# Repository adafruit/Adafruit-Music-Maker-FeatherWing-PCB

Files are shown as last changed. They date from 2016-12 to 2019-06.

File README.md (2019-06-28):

## Adafruit Music Maker FeatherWing PCB

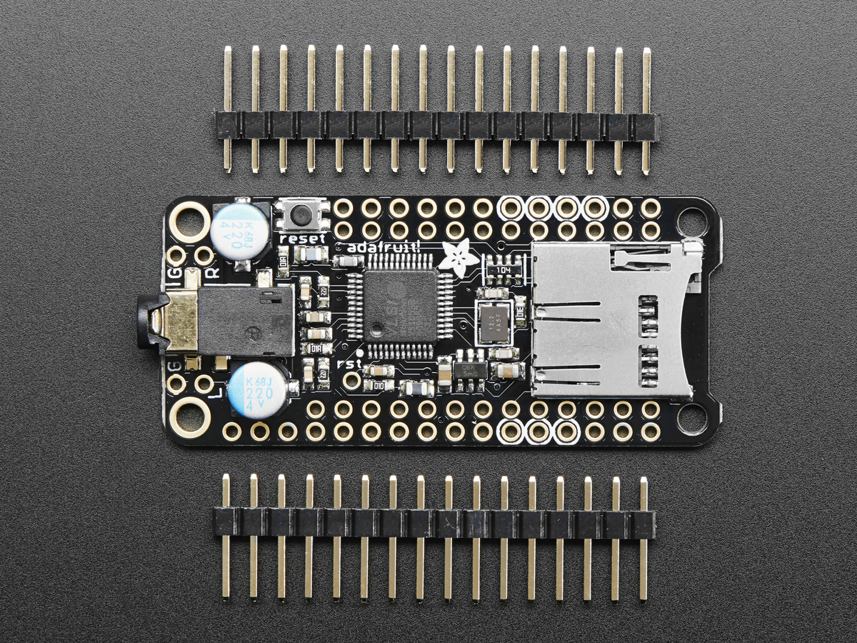
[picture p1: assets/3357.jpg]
<a href="http://www.adafruit.com/products/3357">&nbsp; 
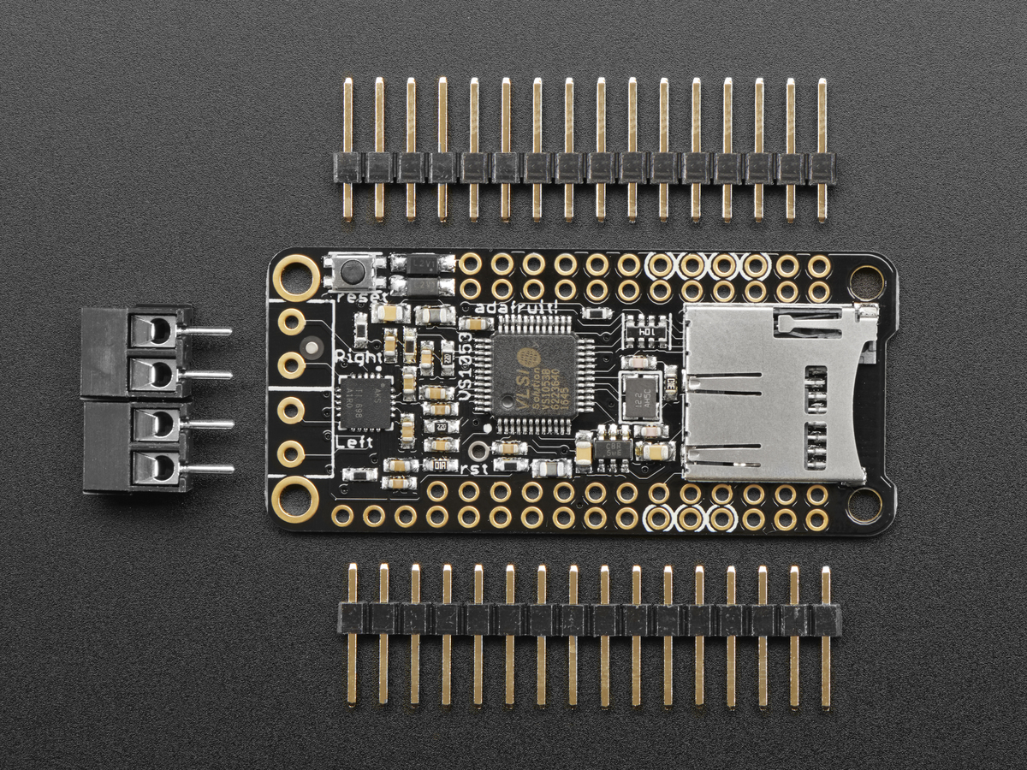
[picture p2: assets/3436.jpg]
<a href="http://www.adafruit.com/products/3436"><br/>
Click a picture to purchase from the Adafruit shop</a>

PCB files for the Adafruit Music Maker FeatherWings. Format is EagleCAD schematic and board layout

For more details, check out the product pages at
  * Music Maker FeatherWing http://www.adafruit.com/products/3357
  * Music Maker FeatherWing with 3W amp http://www.adafruit.com/products/3436

### Description

Bend all audio files to your will with the Adafruit Music Maker FeatherWings! It's a fun-size version of our Music Maker shield for Arduino! This powerful wing features the VS1053, an encoding/decoding (codec) chip that can decode a wide variety of audio formats such as MP3, AAC, Ogg Vorbis, WMA, MIDI, FLAC, WAV (PCM and ADPCM). You can do all sorts of stuff with the audio as well such as adjusting bass, treble, and volume digitally.

All this functionality is implemented in a light-weight SPI interface so that any Feather Board can play audio from an SD card. There's also a special MIDI mode that you can boot the chip into that will read 'classic' 31250Kbaud MIDI data from the UART TX pin and act like a synth/drum machine - there are dozens of built-in drum and sample effects!

What a great musical add-on to your Feather! That's why we spun up this super FeatherWing, perfect for use with any of our Feather Boards! Music playback testing working with ATmega32u4, ATSAMD M0, ESP8266, WICED Teensy 3, and nRF52 Feathers. MIDI playback works with all Feathers but you may need to remove the 'Wing during programming and also for USB-Serial Feathers like the ESP8266 and nRF52 you'll end up re-using the main Serial console for MIDI which can be confusing.

### License

Adafruit invests time and resources providing this open source design, please support Adafruit and open-source hardware by purchasing products from [Adafruit](https://www.adafruit.com)!

Designed by Limor Fried/Ladyada for Adafruit Industries.

Creative Commons Attribution/Share-Alike, all text above must be included in any redistribution. See license.txt for additional details.

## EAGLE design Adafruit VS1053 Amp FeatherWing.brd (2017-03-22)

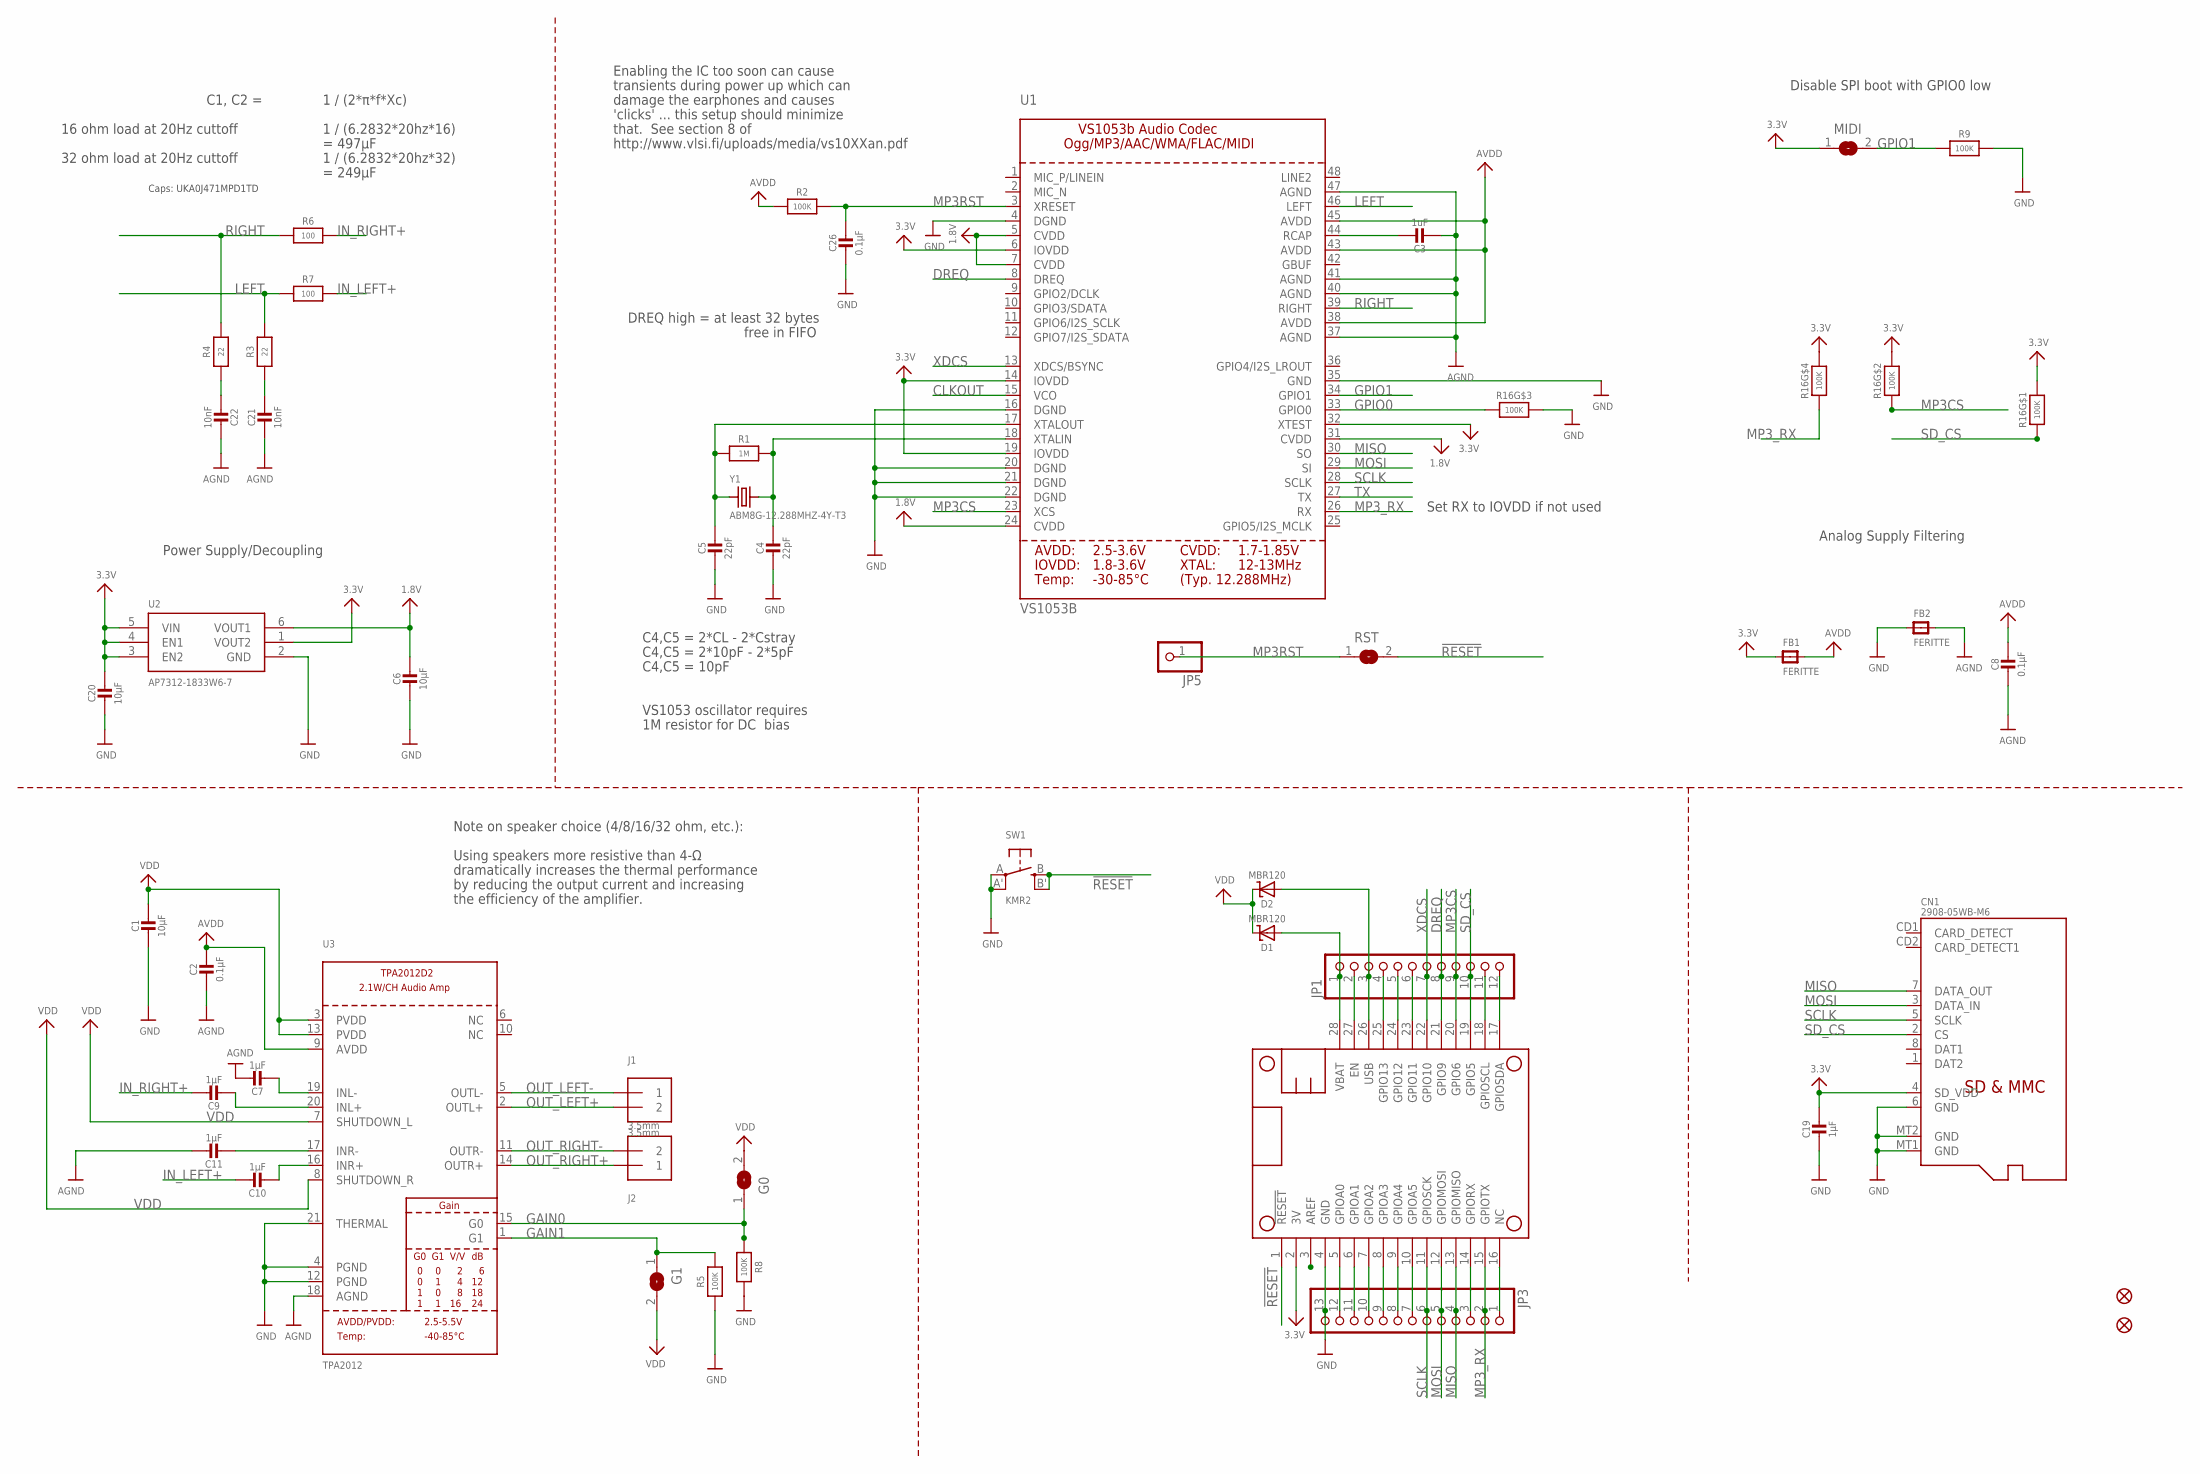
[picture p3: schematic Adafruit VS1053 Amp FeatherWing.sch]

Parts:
C1, C20: 10µF; 0805-NO
C2, C8, C26: 0.1µF; 0603-NO
C3: 1uF; 0603-NO
C4, C5: 22pF; 0603-NO
C6: 10µF; _0805MP
C7, C9, C10, C11, C19: 1µF; 0603-NO
C21, C22: 10nF; 0603-NO
CN1: 2908-05WB-M6; MICROSD
D1, D2: MBR120; SOD-123
FB1, FB2: FERITTE; 0805-NO
FID1, FID2: FIDUCIAL""; FIDUCIAL_1MM
G0, G1: SOLDERJUMPER; SOLDERJUMPER_ARROW_NOPASTE
J1, J2: 3.5mm; TERMBLOCK_1X2-3.5MM
JP1: HEADER-1X12; 1X12_ROUND
JP3: HEADER-1X13; 1X13_ROUND_70
JP5: HEADER-1X1ROUND; 1X01_ROUND
MIDI: SOLDERJUMPER; SOLDERJUMPER_ARROW_NOPASTE
MS1: FEATHERWING_NODIM
R1: 1M; 0603-NO
R2, R5, R8: 100K; 0603-NO
R3, R4: 22; 0603-NO
R6, R7: 100; 0603-NO
R9: 100K; _0603MP
R16: 100K; RESPACK_4X0603
RST: SOLDERJUMPERCLOSED; SOLDERJUMPER_CLOSEDWIRE
SW1: KMR2; BTN_KMR2_4.6X2.8
U1: VS1053B; LQFP48
U2: AP7312-1833W6-7; SOT23-6
U3: TPA2012; WQFN20
Y1: ABM8G-12.288MHZ-4Y-T3; CRYSTAL_3.2X2.5

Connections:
1.8V: C6.1, U1.5 (CVDD), U1.7 (CVDD), U1.24 (CVDD), U1.31 (CVDD), U2.6 (VOUT1)
3.3V: C19.1, C20.1, CN1.4 (SD_VDD), FB1.1, MIDI.1, MS1.2 (3V), R16.5 (2), R16.7 (2), R16.8 (2), U1.6 (IOVDD), U1.14 (IOVDD), U1.19 (IOVDD), U1.32 (XTEST), U2.1 (VOUT2), U2.3 (EN2), U2.4 (EN1), U2.5 (VIN)
!RESET: MS1.1 (!RESET), RST.2, SW1.B (S), SW1.B' (S1)
A: JP3.12, MS1.5 (GPIOA0)
AGND: C2.2, C3.2, C7.1, C8.2, C11.1, C21.2, C22.2, FB2.2, U1.37 (AGND), U1.40 (AGND), U1.41 (AGND), U1.47 (AGND), U3.18 (AGND)
AREF: MS1.3 (AREF)
AVDD: C2.1, C8.1, FB1.2, R2.1, U1.38 (AVDD), U1.43 (AVDD), U1.45 (AVDD), U3.9 (AVDD)
B: JP3.11, MS1.6 (GPIOA1)
C: JP3.10, MS1.7 (GPIOA2)
CLKOUT: U1.15 (VCO)
D: JP3.9, MS1.8 (GPIOA3)
DREQ: JP1.8, MS1.21 (GPIO9), U1.8 (DREQ)
E: JP3.8, MS1.9 (GPIOA4)
EN: JP1.2, MS1.27 (EN)
F: JP3.7, MS1.10 (GPIOA5)
G: JP3.1, MS1.16 (NC)
GAIN0: G0.1, R8.1, U3.15 (G0)
GAIN1: G1.1, R5.2, U3.1 (G1)
GND: C1.2, C4.2, C5.2, C6.2, C19.2, C20.2, C26.2, CN1.6 (GND), CN1.MT1 (GND), CN1.MT2 (GND), FB2.1, JP3.13, MS1.4 (GND), R5.1, R8.2, R9.2, R16.6 (2), SW1.A, SW1.A' (P1), U1.4 (DGND), U1.16 (DGND), U1.20 (DGND), U1.21 (DGND), U1.22 (DGND), U1.35 (GND), U2.2 (GND), U3.4 (PGND), U3.12 (PGND), U3.21 (THERMAL)
GPIO0: R16.3 (1), U1.33 (GPIO0)
GPIO1: MIDI.2, R9.1, U1.34 (GPIO1)
IN_LEFT+: C10.1, R7.1
IN_RIGHT+: C9.1, R6.1
L: JP1.6, MS1.23 (GPIO11)
LEFT: R3.1, R7.2, U1.46 (LEFT)
M: JP1.5, MS1.24 (GPIO12)
MISO: CN1.7 (DATA_OUT), JP3.4, MS1.13 (GPIOMISO), U1.30 (SO)
MOSI: CN1.3 (DATA_IN), JP3.5, MS1.12 (GPIOMOSI), U1.29 (SI)
MP3CS: JP1.9, MS1.20 (GPIO6), R16.2 (1), U1.23 (XCS)
MP3RST: C26.1, JP5.1, R2.2, RST.1, U1.3 (XRESET)
MP3_RX: JP3.2, MS1.15 (GPIOTX), R16.4 (1), U1.26 (RX)
N: JP1.4, MS1.25 (GPIO13)
unnamed: C5.1, R1.1, U1.17 (XTALOUT), Y1.1
unnamed: C4.1, R1.2, U1.18 (XTALIN), Y1.2
unnamed: C3.1, U1.44 (RCAP)
unnamed: C21.1, R3.2
unnamed: C22.1, R4.2
unnamed: C9.2, U3.20 (INL+)
unnamed: C7.2, U3.19 (INL-)
unnamed: C11.2, U3.17 (INR-)
unnamed: C10.2, U3.16 (INR+)
OUT_LEFT+: J1.2, U3.2 (OUTL+)
OUT_LEFT-: J1.1, U3.5 (OUTL-)
OUT_RIGHT+: J2.1, U3.14 (OUTR+)
OUT_RIGHT-: J2.2, U3.11 (OUTR-)
RIGHT: R4.1, R6.2, U1.39 (RIGHT)
SCL: JP1.11, MS1.18 (GPIOSCL)
SCLK: CN1.5 (SCLK), JP3.6, MS1.11 (GPIOSCK), U1.28 (SCLK)
SDA: JP1.12, MS1.17 (GPIOSDA)
SD_CS: CN1.2 (CS), JP1.10, MS1.19 (GPIO5), R16.1
TX: U1.27 (TX)
UART_RX: JP3.3, MS1.14 (GPIORX)
USB: D2.A, JP1.3, MS1.26 (USB)
VBAT: D1.A, JP1.1, MS1.28 (VBAT)
VDD: C1.1, D1.C, D2.C, G0.2, G1.2, U3.3 (PVDD), U3.7 (SHUTDOWN_L), U3.8 (SHUTDOWN_R), U3.13 (PVDD)
XDCS: JP1.7, MS1.22 (GPIO10), U1.13 (XDCS/BSYNC)

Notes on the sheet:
Analog Supply Filtering
C4,C5 = 2*CL - 2*Cstray
C4,C5 = 2*10pF - 2*5pF
C4,C5 = 10pF
VS1053 oscillator requires
1M resistor for DC bias
Set RX to IOVDD if not used
DREQ high = at least 32 bytes
Power Supply/Decoupling
transients during power up which can
damage the earphones and causes
'clicks' ... this setup should minimize
that. See section 8 of
http://www.vlsi.fi/uploads/media/vs10XXan.pdf
Enabling the IC too soon can cause
free in FIFO
Disable SPI boot with GPIO0 low
1 / (2*π*f*Xc)
16 ohm load at 20Hz cuttoff
1 / (6.2832*20hz*16)
C1, C2 =
= 497µF
32 ohm load at 20Hz cuttoff
1 / (6.2832*20hz*32)
= 249µF
Caps: UKA0J471MPD1TD
Using speakers more resistive than 4-Ω
dramatically increases the thermal performance
by reducing the output current and increasing
the efficiency of the amplifier.
Note on speaker choice (4/8/16/32 ohm, etc.):

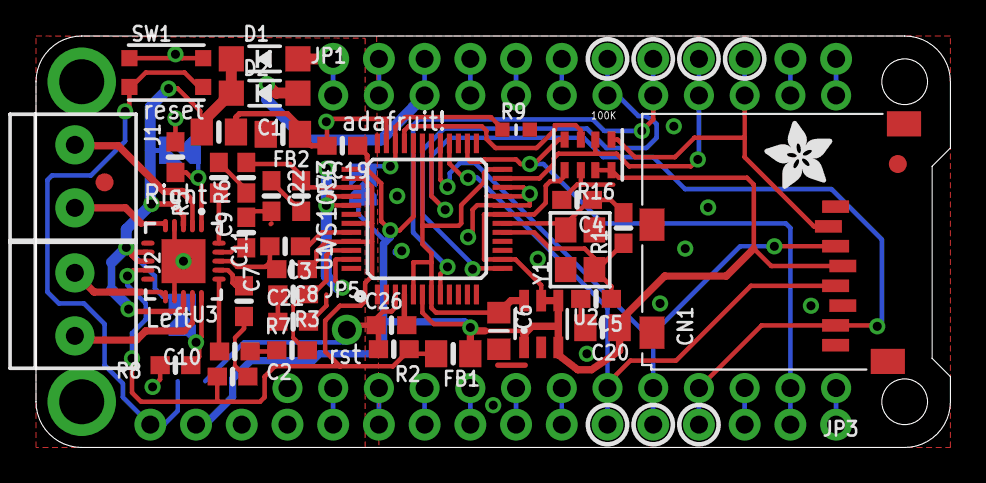
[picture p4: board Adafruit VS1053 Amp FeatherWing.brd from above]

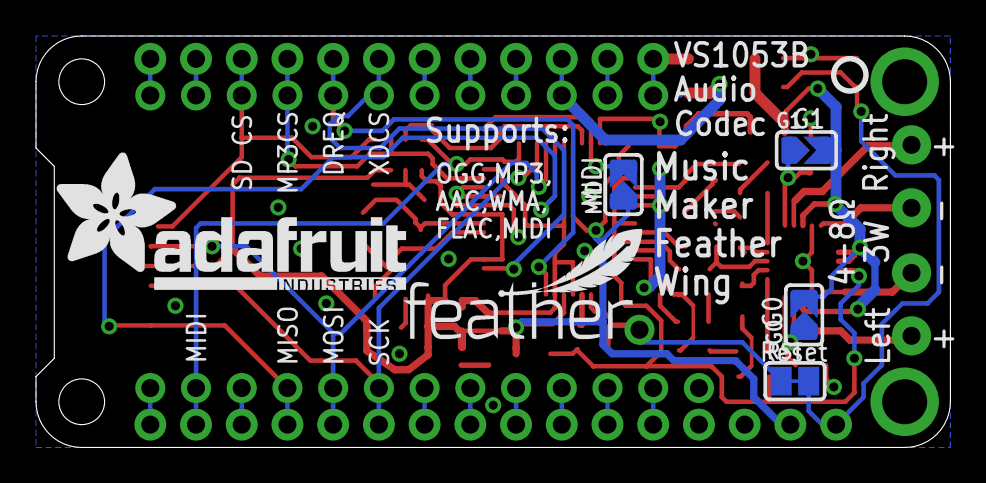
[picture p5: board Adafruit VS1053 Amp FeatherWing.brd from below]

Board: 2 copper layers, 50.8 x 22.9 mm, 52 parts (7 on the bottom side), 53 nets.

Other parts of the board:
U$36: ADAFRUIT_3.5MM
U$37: FEATHERLOGO_SMALL
U$43: PCBFEAT-REV-040
U$55: ADAFRUIT_TEXT_20MM

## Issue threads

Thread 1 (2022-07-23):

PVDD and AVDD must be the same voltage (or else TPA2012 AMP runs hot)

technobly, 2022-07-23:
Hi Adafruit!

I found and fixed a design issue with the "Adafruit VS1053 Amp FeatherWing" version of this FeatherWing.

I had a brand new one of these with the TPA2012 Class-D amplifier and the volume was super low no matter what I did to adjust it.  I felt the TPA2012 AMP and it was blazing hot to the touch.  I figured I killed it with ESD at some point in the past, so I ordered a replacement amp from Digikey.  After swapping it out I had the same issue!

I searched your forums for this and found many people with the same problem, and no resolution as far as I could see:

Search For "amp hot"
https://forums.adafruit.com/search.php?st=0&sk=t&sd=d&sr=posts&keywords=amp+hot&start=75

And find many pages of these:
https://forums.adafruit.com/viewtopic.php?t=136709&hilit=amp+hot
https://forums.adafruit.com/viewtopic.php?t=191462&hilit=amp+hot
https://forums.adafruit.com/viewtopic.php?t=185623&hilit=amp+hot
https://forums.adafruit.com/viewtopic.php?t=181647&hilit=amp+hot
https://forums.adafruit.com/viewtopic.php?t=178464&hilit=amp+hot
https://forums.adafruit.com/viewtopic.php?t=171458&hilit=amp+hot
https://forums.adafruit.com/viewtopic.php?=169776&hilit=amp+hot
https://forums.adafruit.com/viewtopic.php?t=167124&hilit=amp+hot
https://forums.adafruit.com/viewtopic.php?t=166540&hilit=amp+hot
https://forums.adafruit.com/viewtopic.php?t=165319&hilit=amp+hot
https://forums.adafruit.com/viewtopic.php?t=156650&hilit=amp+hot
https://forums.adafruit.com/viewtopic.php?t=144562&hilit=amp+hot
https://forums.adafruit.com/viewtopic.php?t=143768&hilit=amp+hot
...

One thing I see support asking a lot is if customers accidentally short-circuited the speaker outputs.  It seems like this chip has necessary protections for that.
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

The TPA2012 Datasheet: https://www.ti.com/lit/ds/symlink/tpa2012d2.pdf

Shows that the PVDD and AVDD "must be the same voltage"
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

The reference design shows both inputs tied together, sharing 10uF and 1uF
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

TI references "PVDD/AVDD" together as one input:
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

However, on the Music Maker FeatherWing, the AVDD input is tied to 3.3V and does not have as much filtering/decoupling capacitance on it as PVDD does.
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

It's pretty easy to modify the PCB to remove AVDD from 3.3V and jumper the AVDD input to PVDD like so:
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

After doing this mod, my TPA2012 chip is not even warm at full volume and max gain (both G0 and G1 jumpered) with a single 8 ohm speaker.

~The volume is still something to be desired, but with a proper enclosure around the speaker it's much fuller and louder.~
EDIT: Solved this one as well, see #2

Other products that use the TPA2012 or TPA2016 should be looked at as well.  I've seen other forum posts about these being hot unexpectedly as well.

Hope this is helpful :D
Best regards,
Brett Walach

ladyada, 2022-07-25:
iiiiiiiiiiiiiiiinteresting. and yes, totally true! the odd thing about the overheating issue is we could never reproduce the issue - the boards we built were fine, so it seems like it didnt always trigger the overheating.

ive done a quick revision to make rev D: AVDD still exists but is only used by the VS1053 - the TPA has only PVDD connected and gets both capacitors
check it out & we can replace the current stock of boards/pcbs with this new design :)

[VS1053 Amp Wing Rev D.zip](https://github.com/adafruit/Adafruit-Music-Maker-FeatherWing-PCB/files/9185056/VS1053.Amp.Wing.Rev.D.zip)

technobly, 2022-07-25:
@ladyada LGTM!  Super fast turnaround 😸

ladyada, 2023-01-24:
forgot to update - this was implemented

ZevEisenberg, 2023-03-20:
I have a Music Maker with amp that I think has a similar problem. The volume isn't too low, but the amp chip gets super hot, even when audio isn't playing. I bought it in February 2023, but via [this Amazon listing](https://www.amazon.com/gp/product/B07BB7LZRJ/) because Adafruit didn't (and doesn't) have them in stock. Is my board affected? Is it something to worry about? I'm 3D printing an enclosure, so I'm kind of worried about the heat just in terms of not wanting to melt the box it's in 😅

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

Wiring setup and [speaker](https://www.amazon.com/gp/product/B08JCHK7GR):

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

technobly, 2023-03-29:
@ZevEisenberg you can probably make the same modification (cut and jump) I show up above to fix it.  You'll need some good lighting and magnification though.

technobly, 2023-03-29:
You could probably do it with a $5 jeweler's loupe and x-acto knife.  I also highly recommend the [2.25x version of this LED magnifier lamp.](https://www.amazon.com/gp/product/B07MMZ27QK)  Did you order a new one from Adafruit directly? If so it should be the updated design.

Closed 2023-01-24.

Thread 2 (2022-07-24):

RIGHT channel is very quiet (low volume), incorrect R6 (should be 100 ohms)

technobly, 2022-07-24:
> Related to my other issue #1

Yay, I figured out why it was so quiet as well!

I'm sure you've fixed this issue by now, but just in case and/or there are others out there with a quiet RIGHT channel.  Up until now I was just using the RIGHT channel and it was unusually quiet, even after the HOT fix #1.  I tried the LEFT channel by chance and about raised the dead with the volume!!  That's more like it!!

So I measured the audio signals leaving the VS1053B and the RIGHT channel seemed to attenuate to nothing right after R6.

R6 measured 100k ohms, and should be 100 ohms 😸
NOTE: Notice the solder is original.  BTW this MusicMaker FeatherWing was probably purchased 6 year ago!
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

I replaced this incorrectly stuffed R6 with a 120 ohm I had on hand and now we are jammin' 🕺🏼 🎶 🔊

ladyada, 2022-07-25:
kk - this issue was a pick and place error, found/resolved in 2018 (your feather is very old)

Closed 2022-07-25.

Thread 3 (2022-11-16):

Strange error occurs once and again while using Music Maker

IalMazan12, 2022-11-16:
Hello everybody!

I'm developing a build in which I need to play an .mp3 file in the ESP32-based Feather HUZZAH32 board.
In order to get that, I decided to use the Adafruit Music Maker FeatherWing (without Amp) board, and Adafruit VS1053 library.

I started with the example recomended in [official site](https://learn.adafruit.com/adafruit-music-maker-featherwing/play-music). So, after connecting all the pins of both boards, I uploaded the VS1053 library's example "feather_player" without any modification. However, I get the error below:

`Adafruit VS1053 Feather Test
VS1053 found
SD OK!
track002.wav		5299354
track001.wav		5299346
Playing full track 001
Guru Meditation Error: Core  1 panic'ed (Unhandled debug exception).
Debug exception reason: Stack canary watchpoint triggered (dF⸮?)
Core  1 register dump:
PC      : 0x40084583  PS      : 0x00050036  A0      : 0x3ffb097c  A1      : 0x3ffb08bc
A2      : 0x00000029  A3      : 0x3ffbe110  A4      : 0x400845eb  A5      : 0xc0000000
A6      : 0x3ffb097c  A7      : 0x3ffbdc1c  A8      : 0x000000f9  A9      : 0x4008459f
A10     : 0x80000000  A11     : 0x3ffbdf58  A12     : 0x3ffbdf5c  A13     : 0x3ffbdf2c
A14     : 0x00008000  A15     : 0x3ffbdc1c  SAR     : 0x00000001  EXCCAUSE: 0x00000001
EXCVADDR: 0x00008000  LBEG    : 0x40087151  LEND    : 0x40087161  LCOUNT  : 0xfffffffa

Backtrace:0x40084580:0x3ffb08bc |<-CORRUPTED

ELF file SHA256: 0000000000000000

Rebooting...
ets Jul 29 2019 12:21:46

rst:0xc (SW_CPU_RESET),boot:0x13 (SPI_FAST_FLASH_BOOT)
configsip: 0, SPIWP:0xee
clk_drv:0x00,q_drv:0x00,d_drv:0x00,cs0_drv:0x00,hd_drv:0x00,wp_drv:0x00
mode:DIO, clock div:1
load:0x3fff0030,len:1184
load:0x40078000,len:13160
load:0x40080400,len:3036
entry 0x400805e4`

This text is repeated once and again without any change. The only sound you can hear is the one that is generated at start of the sketch.
You can see that the error doesn't start when reading the uSD card: it appears when starts playing a file.

I have tried checking conections, changing the HUZZAH32 board (I got two of them), changing the uSD card, changing audio files format, making all code and conection changes that appears on the [official troubleshooting page](https://learn.adafruit.com/adafruit-music-maker-featherwing/troubleshooting)... But none of them worked. Even more, none of the characters of the error changed.

Could somenone explain what should I do? Why does the error occur?

Thank you very much for help!

Iñigo

mikeysklar, 2025-06-15:
This came up in the [forums](https://forums.adafruit.com/viewtopic.php?p=1058466#p1058466). It was found that D12 was being pulled high and needs to be low to get through bootloading.

You can try a 10k pull resistor to GND or even direct tie to GND which should resolve this on the Feather ESP32 V2. Which while not named directly above is likely the board you are using.

mikeysklar, 2025-07-04:
@ladyada : warning added to guide in playing simple audio sketch. Also added a blurb in the troubleshooting section.

https://learn.adafruit.com/adafruit-music-maker-featherwing/play-music#simple-audio-player-sketch-2144908

https://learn.adafruit.com/adafruit-music-maker-featherwing/troubleshooting#adafruit-esp32-feather-v2-3202465

ps. I don't have permission to close this issue.

ladyada, 2025-07-07:
thanks :)
